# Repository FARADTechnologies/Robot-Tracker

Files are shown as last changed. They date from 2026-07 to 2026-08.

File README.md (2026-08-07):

# Robot Tracker

An end-to-end GNSS vehicle tracker: an ESP32-S3 + A7608E-H device reads its
position, **encrypts it with AES-256-GCM**, and publishes it over the cellular
network via MQTT. A browser dashboard subscribes, decrypts the payload
client-side and shows the vehicle live on a map.

Because the payload is encrypted before it leaves the device, the broker only
ever relays ciphertext — it never sees a real position.

```
[vehicle]  GNSS fix -> JSON -> AES-256-GCM -> MQTT over LTE
                                  |
                            [ MQTT broker ]         relays ciphertext only
                                  |
[browser]  MQTT over WebSocket -> decrypt in page -> live map + history
```

## Features

**Device**
- Multi-constellation GNSS (GPS + GLONASS + BeiDou + Galileo)
- AES-256-GCM payload encryption using the ESP32-S3 hardware accelerator
- Assisted GNSS (`AT+CAGPS`) for a faster, more reliable first fix
- Quality filtering: HDOP gating, impossible-jump rejection, stationary smoothing,
  and an optional HDOP-adaptive Kalman filter
- Adaptive reporting — frequent while moving, sparse while parked
- Store-and-forward buffer so positions survive cellular coverage gaps
- Remote configuration over MQTT (no USB required)
- Every feature can be toggled at runtime for debugging

**Dashboard**
- Live map with heading cone, accuracy circle, trail and dwell markers
- History scrubber with playback, and 15 min / 1 h / 1 day ranges
- Telemetry rail: speed, accuracy (±m and HDOP), satellites, altitude, heading
- Key vault — AES keys are typed in per session and kept in tab memory only
- Serial console (Web Serial) for direct AT access, plus an MQTT command tab
- Light and dark themes, English and Turkish, responsive down to phone size

## Repository layout

```
Firmware/
  gps_tracker/       main tracker firmware (config.example.h -> config.h)
  a7608_at_test/     modem bring-up sketch: AT, SIM, network, GNSS, HTTP
  gps/               minimal GNSS read example
  zenith_tracker/    early dashboard prototype
web/
  zenith.html        the dashboard (single file, no build step)
  config.example.js  copy to config.js and set broker + topics
tools/
  listen.py          subscribe and print decrypted positions
  send_command.py    send a downlink command to the device
  mock_walk.py       publish a fake track to exercise the UI
Mechanical/CAD/      enclosure and mounting design
docs/                hardware notes
```

## Hardware

| Part | Notes |
| --- | --- |
| ESP32-S3-N16R8 | 16 MB flash, 8 MB OPI PSRAM, hardware AES |
| A7608E-H | LTE Cat-4 modem with built-in multi-constellation GNSS |
| GNSS antenna | Ceramic patch — **mount it on a ≥70 × 70 mm ground plane** |
| LTE antenna | Full band 698–960 / 1710–2690 MHz |
| Power | 4S Li-ion pack + BMS -> buck converter -> 5 V rail |

Wiring between the two boards:

| ESP32-S3 | A7608E-H |
| --- | --- |
| GPIO15 (TX) | RXD |
| GPIO16 (RX) | TXD |
| GND | GND |

See [docs/hardware.md](docs/hardware.md) for power notes and accuracy tips.

## Getting started

### 1. Firmware

```bash
cp Firmware/gps_tracker/config.example.h Firmware/gps_tracker/config.h
# edit config.h: APN, broker, client id, topics, and your own AES key
openssl rand -hex 32          # generate a key
```

Build and upload with [arduino-cli](https://arduino.github.io/arduino-cli/):

```bash
arduino-cli core install esp32:esp32
arduino-cli compile --fqbn esp32:esp32:esp32s3:PSRAM=opi,FlashSize=16M,PartitionScheme=app3M_fat9M_16MB,CDCOnBoot=default,USBMode=hwcdc Firmware/gps_tracker
arduino-cli upload -p COM3 --fqbn esp32:esp32:esp32s3:PSRAM=opi,FlashSize=16M,PartitionScheme=app3M_fat9M_16MB,CDCOnBoot=default,USBMode=hwcdc Firmware/gps_tracker
```

The board exposes two USB-C ports: use the one wired to the USB-serial bridge for
flashing, and keep `CDCOnBoot=default` so the serial monitor works there.

### 2. Dashboard

```bash
cp web/config.example.js web/config.js    # set broker + topics
```

Open `web/zenith.html` in Chrome, Edge or Brave (Web Serial and Web Crypto are
required; both need a Chromium browser). Press **Connect**, then open the key
vault (🗝) and paste the device's 64-hex key. Nothing is stored on disk.

### 3. Tools

```bash
export TRACKER_KEY=<64 hex>
export TRACKER_TOPIC=yourprefix/trk01/pos
python tools/listen.py
```

## Remote configuration

Publish JSON to the device's command topic — from the dashboard's MQTT console
or with `tools/send_command.py`:

| Command | Effect |
| --- | --- |
| `{"interval":5}` | reporting period in seconds |
| `{"gnssms":1000}` | GNSS fix rate in ms (200–10000) |
| `{"hdopmax":2.5}` | reject fixes worse than this HDOP |
| `{"hdopgate":0}` | disable HDOP filtering |
| `{"statlock":0}` | disable stationary smoothing |
| `{"jumprej":0}` | disable jump rejection |
| `{"kalman":1}` | enable the Kalman filter |
| `{"agps":1}` | enable assisted GNSS |
| `{"antbias":0}` | stop feeding DC to the antenna (passive antenna) |
| `{"antmv":1800}` | antenna bias voltage in mV — also sets its LNA gain |
| `{"rlog":1}` | mirror the console to the log topic |
| `{"wifi":0}` | switch Wi-Fi and OTA off |
| `{"verbose":1}` | echo raw AT traffic to USB |
| `{"cmd":"report"}` | report position immediately |

Commands are themselves AES-256-GCM encrypted and carry a strictly increasing
`seq`, so the device rejects any command that is forged or replayed. The device
echoes its live settings back in the telemetry payload, so a command is confirmed
by the next message.

## Working without a cable

Once the tracker is mounted, USB is inconvenient. Three channels replace it:

- **Firmware over Wi-Fi.** The board joins the network named in `config.h`, or
  hosts one with that name if there is nothing to join, and listens for OTA:
  ```bash
  arduino-cli upload -p <device-ip> --protocol network --fqbn <same fqbn> Firmware/gps_tracker
  ```
  Joining an existing network is the better setup — hosting one means the laptop
  has to leave its own network to reach the board.
- **Console over MQTT.** `{"rlog":1}` mirrors log lines to the log topic,
  encrypted like everything else. Off by default because it costs airtime.
- **Console over USB.** Type a command as JSON, or send a raw `AT+...` straight
  to the modem. No sequence number is required there — the cable is already
  physical access, and it is the channel that still works when the radio link is
  the broken thing.

Telemetry carries `vbat`, the modem's supply voltage. Watch it: below about
3.7 V the LTE transmit bursts start failing and the modem drops off the network
before anything else visibly breaks.

## Security model

- **Confidentiality + authenticity both directions.** Positions (uplink) and
  commands (downlink) are AES-256-GCM. The broker only ever relays ciphertext, and
  the GCM tag means neither side accepts a forged or tampered message.
- **Replay protection.** Every frame carries a monotonic `seq`. The device rejects
  commands whose seq does not increase (counter persisted in NVS, so it survives
  reboots), and the dashboard drops stale or out-of-order positions.
- **Per-device keys.** Each device gets its own AES-256 key, so one leaked key
  cannot expose the rest.
- **Keys never committed.** `config.h` and `web/config.js` are untracked. The
  dashboard holds a key in tab memory only — never in localStorage, never shown
  back in plaintext. For the strongest setup keep keys offline (on paper) and type
  them into the vault per session.
- **Subresource Integrity.** The dashboard's CDN dependencies are pinned with
  SRI hashes, so a compromised CDN cannot inject code into a page that handles keys.

## Accuracy notes

Reported accuracy tracks HDOP closely (roughly ±HDOP × 5 m). With a clear view of
the sky the device typically sees 30+ satellites at HDOP below 1.5.

The single biggest cheap improvement is the antenna ground plane: a bare ceramic
patch on a small PCB loses several dB of gain and, more importantly, its circular
polarisation degrades — which is exactly what rejects reflected (multipath)
signals. Mount the patch on a metal plate of at least 70 × 70 mm, ceramic facing
the sky. An active antenna with a built-in LNA is the next step up.

## Roadmap

- IMU dead reckoning for tunnels and urban canyons
- Server-side map matching and persistent history (Supabase, then a dedicated backend)
- Authenticated broker with TLS, multi-device management
- Keys burned into the ESP32-S3 eFuse so firmware cannot read them back
- Geofencing and alerts, battery and ignition telemetry

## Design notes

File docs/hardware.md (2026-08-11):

# Hardware notes

## Power

```
4S Li-ion pack (12.8–16.8 V) -> BMS (4S 40A) -> LM2596 buck -> 5.15 V
                                                     |
                            star split at the buck output, separate wires:
                                     ├── ESP32-S3 board 5Vin
                                     └── A7608E-H breakout V
```

The modem's ~2 A LTE transmit bursts must **not** flow through the ESP32 board —
split the rail at the buck output and run separate pairs to each board. Measured
5.06 V at the common point under load.

### Protection board

The 4S board (marked `4S 40A`, `YS-Z1053`) carries two groups of pads that are
easy to confuse:

| Pads | Purpose |
| --- | --- |
| `0V` `4.2V` `8.4V` `12.6V` `16.8V` | balance and sense taps, one per cell junction |
| `J1` (+) `J2` (−) | the output port |

There is no separate charge terminal, so charge and discharge share `J1`/`J2`.
Both the buck converter and the charging socket hang off those two pads.

The taps double as the pack connection — `16.8V` is the pack positive and `0V`
the negative, so there is no extra `B+` wire. Verify them with a meter before
trusting the pack: each adjacent pair should read one cell, and the spread
between cells should stay under 0.1 V. Measured 2026-08-11 with the tracker
running: 3.66 / 3.66 / 3.64 / 3.72 V, pack 14.57 V, cells within 0.08 V.

That same measurement showed **14.14 V at `J1`/`J2` against 14.57 V at the pack**
— a 0.4 V loss through the board at roughly 100 mA, which implies a poor joint
rather than the MOSFETs. Worth reflowing when the 5 V wiring is soldered.

A protection board is not a charger. It cuts off on overcharge, over-discharge
and overcurrent, but it produces no charging profile of its own — the source
still has to supply a proper 16.8 V constant-current/constant-voltage curve.

A bulk capacitor (≈1000 µF) across the 5 V rail near the modem is recommended.
Without it, LTE bursts can dip the rail; if the ESP32 reboots unexpectedly the
firmware prints the reset reason at boot, so look for `BROWNOUT` there.

## Serial links

| ESP32-S3 | A7608E-H | Note |
| --- | --- | --- |
| GPIO15 | RXD | 3.3 V TTL, no level shifter needed |
| GPIO16 | TXD | |
| GND | GND | common ground required |

Modem default baud rate is 115200 and the AT set is SIM7600-compatible.

The dev board has two USB-C connectors:

- **UART port** (via the USB-serial bridge) — use this for flashing and the
  serial monitor, with `CDCOnBoot=default`.
- **Native USB port** (ESP32-S3 USB-Serial/JTAG) — works too, but then the build
  needs `CDCOnBoot=cdc` or the monitor stays blank.

## Antennas

Two separate connectors: one for LTE, one for GNSS. **Never transmit without the
LTE antenna attached.**

The GNSS ceramic patch needs a ground plane to perform. On a bare breakout the
plane is only the tiny PCB, which costs 2–3 dB of gain, shifts the centre
frequency, and degrades the antenna's right-hand circular polarisation towards
linear. That polarisation is what rejects reflected signals, so a small plane
directly worsens multipath error — the wandering you see in built-up areas.

Mount the patch on a metal plate of at least 70 × 70 mm with the ceramic facing
the sky, away from metal and from the vehicle body edge.

To tell an active antenna (with an internal LNA) from a passive one, measure
resistance between the coax centre and shield: a passive patch reads a short or
an open and is symmetric, while an active one reads a few hundred ohms to a few
kΩ and changes when the probes are reversed.

### Powering an active antenna

The module feeds DC to the antenna over the coax from its `VDD_AUX` pin, and an
active antenna is the module's default assumption. Two AT commands control it:

| Command | Effect |
| --- | --- |
| `AT+CVAUXS=1` / `=0` | enable or disable the bias |
| `AT+CVAUXV=<mV>` | bias voltage: 1200, 1250, 1700, 1800, 1850, 1900, 2500–3300 |

Turn the bias **off** for a passive antenna. The firmware exposes both as
`{"antbias":0|1}` and `{"antmv":1800}`.

The voltage matters for more than power: on most active antennas it also sets the
LNA gain. The module wants **under 18 dB total gain** at its port (its reference
figure is a 20 dB LNA), so a high-gain antenna on a long coax can overshoot and
compress the front end. Subtract the cable loss (RG174 is roughly 1 dB/m at
1.5 GHz) from the antenna's LNA gain, and drop the bias voltage if the result is
still well above 18 dB.

### Fitting an antenna with the wrong connector

Antennas often ship with SMA while the module board uses u.FL (IPEX MHF-I). Chain
them as **coax → SMA male → SMA female-to-u.FL pigtail → board**. A u.FL connector
cannot go directly onto RG174: u.FL is made for 1.13 mm micro-coax, RG174 is 2.8 mm.

Never improvise a splice at 1.5 GHz. A twisted joint wrecks the 50 Ω impedance and
throws away more than the antenna gains. Fit a proper connector, then check for a
short between centre and shield before plugging it into the module — a shorted
antenna shorts the module's bias supply.

Cable length is a design knob, not just a nuisance: RG174 costs roughly 1 dB/m at
1.5 GHz, which usefully offsets a high-gain active antenna. Around 1 m of cable
with the bias at 1800 mV lands close to the module's recommended input level.

### Antenna passband and constellations

Check the antenna's passband against the constellations you want. The module
receives GPS/Galileo at 1575.42 MHz, GLONASS at 1597.5–1605.8 MHz, and BeiDou B1I
at 1561.098 MHz. A GPS/GLONASS antenna specified from 1574 MHz upwards covers the
first two but filters BeiDou out — so switching antennas can change which
constellations appear in `AT+CGNSSINFO`, not just the signal quality.

## Status LED (NETLIGHT)

| Pattern | Meaning |
| --- | --- |
| Steady on | searching for network |
| 200 ms on / 200 ms off | registered on LTE, data ready |
| 800 ms on / 800 ms off | registered on 2G/3G |
| Off | no power or asleep |

## Accuracy checklist

1. Ground plane under the GNSS patch, clear view of the sky.
2. Assisted GNSS enabled (`AT+CAGPS`) — costs only tens of kB, valid for days.
3. HDOP gating on; reported accuracy is roughly ±HDOP × 5 m.
4. Raise the fix rate (`{"gnssms":1000}`) — commercial trackers run at 1–10 Hz.
5. Add an IMU for dead reckoning where the sky is blocked.

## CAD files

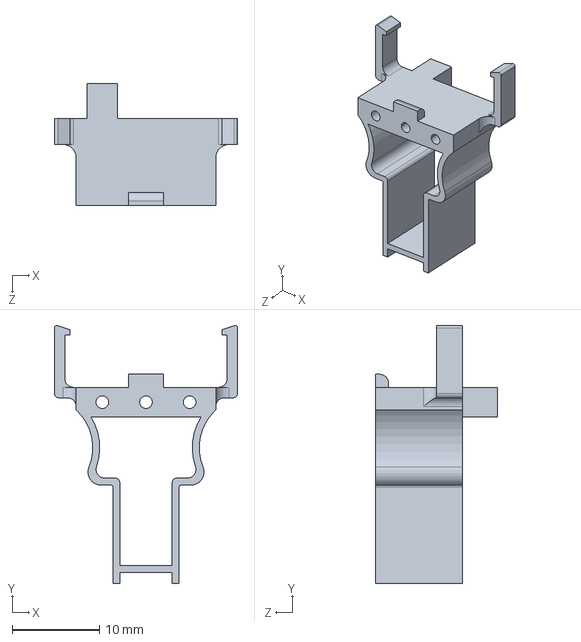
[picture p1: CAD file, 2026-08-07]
Mechanical/CAD/Assembly/batteryhold530-0415.stp.SLDPRT
21.0 x 29.6 x 14.0 mm

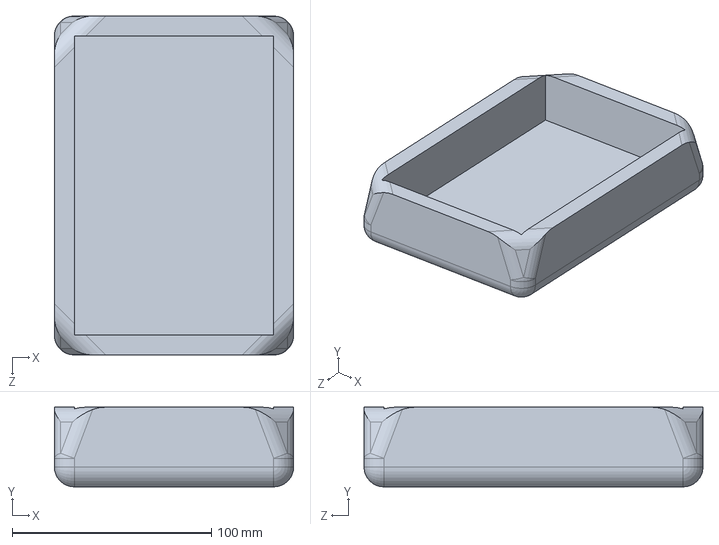
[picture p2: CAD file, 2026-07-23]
Mechanical/CAD/V1/Gövde.SLDPRT
120.0 x 40.0 x 170.0 mm

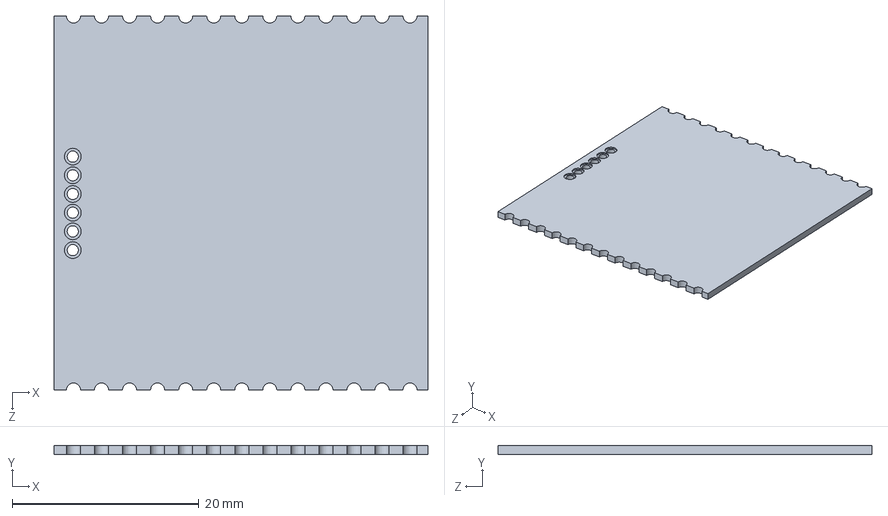
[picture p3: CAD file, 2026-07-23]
Mechanical/CAD/V1/A7608H Plata.SLDPRT
40.0 x 1.00 x 40.0 mm

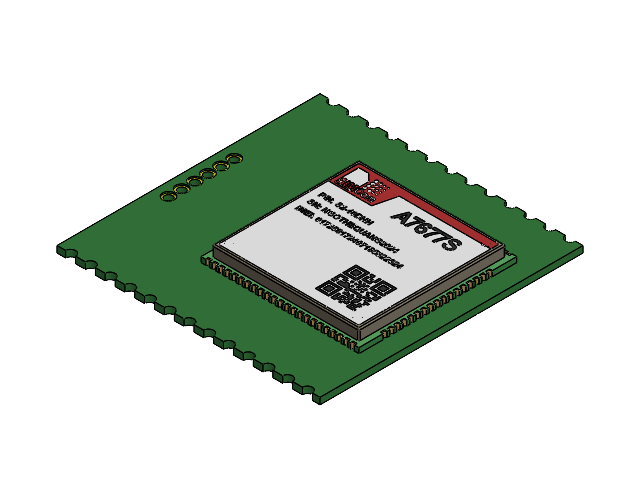
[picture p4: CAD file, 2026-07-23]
Mechanical/CAD/V1/A7608H Module.SLDASM
A7677S
A7608H Plata

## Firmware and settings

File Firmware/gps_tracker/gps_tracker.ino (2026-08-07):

/*
 * GPS Tracker - Phase 3 firmware
 * ESP32-S3-N16R8 + A7608E-H
 *
 * Pipeline: GNSS fix -> compact JSON -> AES-256-GCM -> base64 -> MQTT over LTE.
 * Payload is ciphertext, so even a public broker is a zero-knowledge relay.
 *
 * Phase 3 adds (for real-world / rural use):
 *  - ADAPTIVE REPORTING: fast cadence while the vehicle moves, slow while parked
 *    (+ an immediate report on every moving<->parked transition). Saves data.
 *  - STORE-AND-FORWARD: if a publish fails (no coverage), the reading is queued
 *    in a RAM ring buffer with its own GNSS timestamp; the queue is flushed
 *    (oldest first) once the link is back. No positions lost in rural gaps.
 *  - AUTO-RECOVER: re-power GNSS if it drops (CGNSSINFO -> ERROR), and
 *    re-establish MQTT if a publish fails.
 *
 * Working without USB:
 *  - Firmware goes over Wi-Fi (ArduinoOTA) once the board has joined a network,
 *    so the board only needs power. Wi-Fi is a bench convenience; the tracker
 *    still works with it switched off.
 *  - Logs can be mirrored to an MQTT topic (encrypted like everything else), so
 *    the console is readable from anywhere. Off by default to save airtime.
 *
 * Board settings (upload via right "COM" port = CH343 = COM3):
 *   FQBN esp32:esp32:esp32s3 PSRAM=opi FlashSize=16M CDCOnBoot=default
 *        USBMode=hwcdc UploadSpeed=921600
 * Blob published = base64( IV(12) || ciphertext || GCM-tag(16) )  (Web-Crypto compatible)
 */

#include <math.h>
#include <WiFi.h>
#include <WebServer.h>
#include <ArduinoOTA.h>
#include <Preferences.h>
#include "esp_system.h"
#include "mbedtls/gcm.h"
#include "mbedtls/base64.h"

// ---------------- config ----------------
#define MODEM_BAUD   115200
#define MODEM_RX_PIN 16
#define MODEM_TX_PIN 15

// Private settings live in config.h (APN, broker, client id, topics, DEVICE_ID and
// the 32-byte AES_KEY). That file is untracked — copy config.example.h to config.h
// and fill in your own values before building.
#include "config.h"

// Adaptive cadence
// NOTE: TEST values (frequent, so the web-app trail/trajectory is visible while
// walking). For data-saving production use: MOVING_MS 20000 / PARKED_MS 300000 / MOVE_DIST_M 12.
#define MOVE_DIST_M    5.0         // >5 m between 3 s fixes => moving
#define GNSS_POLL_MS   3000UL

// Store-and-forward
#define BUF_CAP        240         // queued readings when offline (~240 * ~130 B)

HardwareSerial &Modem = Serial1;

// state
bool     gnssPowered = false;
bool     mqttUp      = false;
uint32_t lastGnssPoll = 0;
uint32_t lastReport   = 0;
uint32_t lastMqttTry  = 0;
// Modem supply voltage. Below ~3.7 V the LTE transmit bursts start failing and
// the modem silently drops off the network, so this is worth watching.
float    vbat = 0;
uint32_t lastVbat = 0;
uint32_t movMs = 1000, parkMs = 1000;  // report interval (ms); adjustable via MQTT {"interval":sec}
String   rxAccum;                       // accumulates modem bytes for downlink parsing

/* ---- ACCURACY FEATURES: every one runtime-toggleable for debugging ----
   Downlink: {"agps":0|1,"hdopgate":0|1,"statlock":0|1,"jumprej":0|1,"hdopmax":3.0}
   Also {"cmd":"agpsnow"|"lbs"|"report"}                                        */
bool  F_AGPS     = true;    // AT+CAGPS assisted GNSS (ephemeris over LTE, tiny data)
bool  F_HDOPGATE = true;    // drop fixes whose HDOP is too poor
bool  F_STATLOCK = true;    // heavy smoothing while parked (kills wander)
bool  F_JUMPREJ  = true;    // reject physically impossible jumps
bool  F_LBS      = false;   // cell-tower fallback (off until verified on Azercell)
bool  F_KALMAN   = false;   // 1-D Kalman per axis, HDOP-adaptive (test outdoors before enabling)
bool  F_VERBOSE  = false;   // echo raw AT traffic to USB. OFF keeps the console readable at 1 Hz.
/* An active GNSS antenna is powered by DC on the coax (the module's VDD_AUX pin).
   The voltage also sets the antenna's LNA gain, so it is the knob that matches the
   antenna to the module's recommended input level (< 18 dB total, after cable loss).
   Turn the bias OFF for a passive antenna — SIMCom explicitly recommends that. */
bool  F_ANTBIAS  = true;
int   ANT_MV     = 3000;    // allowed: 1200,1250,1700,1800,1850,1900,2500..3300
/* Bench conveniences so the board never has to be tethered to USB:
   F_WIFI  — join Wi-Fi at boot and accept OTA firmware uploads
   F_RLOG  — mirror the console to an MQTT topic (encrypted, costs airtime) */
bool  F_WIFI     = true;
bool  F_RLOG     = false;
bool  otaBusy    = false;   // pause the modem loop while flashing
bool  otaReady   = false;   // true once the OTA port is listening (station OR hosted network)
/* When the radio link dies there is otherwise no way to ask the device what is
   wrong, even with Wi-Fi working. This serves that answer over HTTP. */
WebServer http(80);
bool  httpReady  = false;
String logBuf;
uint32_t lastLogPub = 0;
double kfLat = 0, kfLon = 0, kfP = 100;   // filter state + covariance
float HDOP_MAX   = 3.0;     // reject above this
float JUMP_MAX_MPS = 60.0;  // 216 km/h — anything faster is noise
uint32_t rejCount = 0, lastFixMs = 0;

/* Replay protection. Both directions carry a strictly increasing sequence number.
   Counters survive reboots via NVS, so an attacker cannot replay an old frame
   after power-cycling the device. Uplink counters are reserved in blocks to keep
   flash wear low at 1 Hz reporting. */
Preferences prefs;
uint32_t upSeq = 0, upSeqPersisted = 0, cmdRejected = 0;
// Command sequence numbers are wall-clock milliseconds, which overflow 32 bits.
uint64_t lastCmdSeq = 0;
#define SEQ_BLOCK 100
/* A restart looks exactly like a coverage gap from the outside, so count them
   and send the number along. A jump in this value explains a hole in the track
   that would otherwise be blamed on the sky. */
uint32_t bootCount = 0;
uint32_t lastBeat = 0;      // heartbeat while there is no fix
uint32_t gnssMs = 1000;     // GNSS fix rate (ms). Commercial trackers run 1-10 Hz; we were at 0.33 Hz.

bool   haveFix = false;
double fixLat = 0, fixLon = 0;
String fixAlt, fixSpd, fixHdop, fixUtc, fixDate, fixSats;

bool   moving = false;              // current motion state
bool   havePrevFix = false;
double prevLat = 0, prevLon = 0;    // anchor for the multi-second motion window
uint32_t prevRefMs = 0, stillSince = 0;
bool   reportedOnce = false;        // force one report on the very first fix

// ring buffer of plaintext JSON payloads (encrypted fresh at send time)
String  qbuf[BUF_CAP];
int     qHead = 0, qCount = 0;

// Print a console line and, when remote logging is on, queue it for the log
// topic so the same message is readable without a USB cable.
void say(const String &s) {
  Serial.println(s);
  if (!F_RLOG) return;
  logBuf += s; logBuf += '\n';
  if (logBuf.length() > 1400) logBuf.remove(0, logBuf.length() - 1400);
}

// Modem commands block for seconds at a time. Servicing OTA inside those waits
// keeps the board answerable to a firmware upload at any moment, instead of only
// in the gaps between commands.
/* Modem commands block for tens of seconds, and while the SIM is missing the
   loop spends nearly all its time inside them — so OTA and HTTP have to be
   served from in here or they are never served at all. The depth counter keeps
   that safe: it marks when a command is in flight so the /at endpoint declines
   rather than talking over it on the same UART. */
int modemDepth = 0;
struct ModemLock { ModemLock() { modemDepth++; } ~ModemLock() { modemDepth--; } };

inline void otaPump() {
  if (otaReady) ArduinoOTA.handle();
  if (httpReady) http.handleClient();
}

// ---------------- AT helpers ----------------
bool waitFor(const char *token, uint32_t timeoutMs, String &out) {
  uint32_t start = millis(); out = "";
  while (millis() - start < timeoutMs) {
    while (Modem.available()) {
      char c = (char)Modem.read(); out += c; if (F_VERBOSE) Serial.write(c);
      if (out.indexOf(token) >= 0) return true;
    }
    otaPump();
    delay(3);
  }
  return false;
}

bool sendAT(const char *cmd, const char *expect, uint32_t timeoutMs) {
  ModemLock lk;
  while (Modem.available()) Modem.read();
  if (F_VERBOSE) { Serial.print("\r\n>> "); Serial.println(cmd); }
  Modem.print(cmd); Modem.print("\r\n");
  String out; bool matched = (expect == nullptr || expect[0] == '\0');
  uint32_t start = millis();
  while (millis() - start < timeoutMs) {
    while (Modem.available()) {
      char c = (char)Modem.read(); out += c; if (F_VERBOSE) Serial.write(c);
      if (!matched && out.indexOf(expect) >= 0) matched = true;
    }
    if ((out.indexOf("OK\r\n") >= 0 || out.indexOf("ERROR") >= 0) && matched) break;
    otaPump();
    delay(3);
  }
  return matched;
}

// Send a command and hand back the modem's raw reply, for answers that need parsing.
String atReply(const char *cmd, uint32_t timeoutMs) {
  ModemLock lk;
  while (Modem.available()) Modem.read();
  if (F_VERBOSE) { Serial.print("\r\n>> "); Serial.println(cmd); }
  Modem.print(cmd); Modem.print("\r\n");
  String out; uint32_t start = millis();
  while (millis() - start < timeoutMs) {
    while (Modem.available()) { char c = (char)Modem.read(); out += c; if (F_VERBOSE) Serial.write(c); }
    if (out.indexOf("OK\r\n") >= 0 || out.indexOf("ERROR") >= 0) break;
    otaPump();
    delay(3);
  }
  return out;
}

bool sendPrompted(const String &cmd, const uint8_t *data, size_t len) {
  ModemLock lk;
  while (Modem.available()) Modem.read();
  if (F_VERBOSE) { Serial.print("\r\n>> "); Serial.println(cmd); }
  Modem.print(cmd); Modem.print("\r\n");
  String r;
  if (!waitFor(">", 3000, r)) return false;
  Modem.write(data, len);
  return waitFor("OK", 5000, r);
}

// ---------------- crypto ----------------
size_t encryptPayload(const String &plain, uint8_t *out, size_t outCap) {
  const size_t ivLen = 12, tagLen = 16;
  size_t ptLen = plain.length();
  if (ivLen + ptLen + tagLen > outCap) return 0;
  uint8_t *iv = out, *ct = out + ivLen, *tag = out + ivLen + ptLen;
  for (size_t i = 0; i < ivLen; i++) iv[i] = (uint8_t)(esp_random() & 0xFF);
  mbedtls_gcm_context gcm; mbedtls_gcm_init(&gcm);
  if (mbedtls_gcm_setkey(&gcm, MBEDTLS_CIPHER_ID_AES, AES_KEY, 256) != 0) { mbedtls_gcm_free(&gcm); return 0; }
  int rc = mbedtls_gcm_crypt_and_tag(&gcm, MBEDTLS_GCM_ENCRYPT, ptLen, iv, ivLen, nullptr, 0,
                                     (const uint8_t*)plain.c_str(), ct, tagLen, tag);
  mbedtls_gcm_free(&gcm);
  return rc == 0 ? ivLen + ptLen + tagLen : 0;
}

String base64Of(const uint8_t *data, size_t len) {
  size_t need = 0; mbedtls_base64_encode(nullptr, 0, &need, data, len);
  uint8_t *buf = (uint8_t*)malloc(need + 1); if (!buf) return String();
  size_t wrote = 0; mbedtls_base64_encode(buf, need + 1, &wrote, data, len); buf[wrote] = 0;
  String s = String((char*)buf); free(buf); return s;
}

// Decrypt a base64( IV(12) || ciphertext || tag(16) ) blob. Returns "" if the
// GCM tag does not verify — i.e. wrong key or tampered/forged command.
String decryptPayload(const String &b64) {
  size_t inLen = b64.length();
  uint8_t *raw = (uint8_t*)malloc(inLen); if (!raw) return String();
  size_t rawLen = 0;
  if (mbedtls_base64_decode(raw, inLen, &rawLen, (const uint8_t*)b64.c_str(), inLen) != 0 ||
      rawLen < 12 + 16 + 1) { free(raw); return String(); }
  const size_t ivLen = 12, tagLen = 16, ptLen = rawLen - ivLen - tagLen;
  uint8_t *iv = raw, *ct = raw + ivLen, *tag = raw + ivLen + ptLen;
  uint8_t *pt = (uint8_t*)malloc(ptLen + 1); if (!pt) { free(raw); return String(); }
  mbedtls_gcm_context gcm; mbedtls_gcm_init(&gcm);
  int rc = -1;
  if (mbedtls_gcm_setkey(&gcm, MBEDTLS_CIPHER_ID_AES, AES_KEY, 256) == 0)
    rc = mbedtls_gcm_auth_decrypt(&gcm, ptLen, iv, ivLen, nullptr, 0, tag, tagLen, ct, pt);
  mbedtls_gcm_free(&gcm);
  String out;
  if (rc == 0) { pt[ptLen] = 0; out = String((char*)pt); }
  free(raw); free(pt);
  return out;                                   // empty on auth failure
}

// ---------------- geo ----------------
double distMeters(double la1, double lo1, double la2, double lo2) {
  const double R = 6371000.0, d = 0.017453292519943295;
  double dla = (la2 - la1) * d, dlo = (lo2 - lo1) * d;
  double a = sin(dla/2)*sin(dla/2) + cos(la1*d)*cos(la2*d)*sin(dlo/2)*sin(dlo/2);
  return 2 * R * asin(sqrt(a));
}

// ---------------- LTE + GNSS ----------------
int splitFields(const String &s, String f[], int maxF) {
  int n = 0, start = 0;
  while (n < maxF) {
    int c = s.indexOf(',', start);
    if (c < 0) { f[n++] = s.substring(start); break; }
    f[n++] = s.substring(start, c); start = c + 1;
  }
  return n;
}

bool lteUp() {
  bool alive = false;
  for (int i = 0; i < 10 && !alive; i++) { alive = sendAT("AT", "OK", 1500); if (!alive) delay(800); }
  if (!alive) return false;
  sendAT("ATE0", "OK", 1500);
  sendAT("AT+CPIN?", "READY", 3000);
  sendAT("AT+CMGD=1,4", nullptr, 5000);   // clear SMS storage; a full store blocks the modem
  sendAT("AT+CGDCONT=1,\"IP\",\"" APN "\"", "OK", 3000);
  // Wait for real packet registration. MQTT cannot connect before the network
  // is attached, and after a cold boot that takes tens of seconds.
  for (int i = 0; i < 40; i++) {
    String r = atReply("AT+CGREG?", 2000);
    int k = r.indexOf("+CGREG:");
    if (k >= 0) {
      int c = r.indexOf(',', k);
      if (c > 0) {
        int st = r.substring(c + 1, c + 2).toInt();     // 1 = home, 5 = roaming
        if (st == 1 || st == 5) { say(String("[lte] registered after ") + i + " s"); return true; }
      }
    }
    delay(1000);
  }
  say("[lte] no packet registration yet");
  return false;
}

void gnssOn() {
  sendAT("AT+CGNSSPWR=1", "OK", 5000);
  String r; waitFor("READY!", 15000, r);
  gnssPowered = true;
}

// Poll one CGNSSINFO; updates fix + motion state. Auto-recovers GNSS if it dropped.
void pollGnss() {
  String resp;
  while (Modem.available()) Modem.read();
  if (F_VERBOSE) Serial.print("\r\n>> AT+CGNSSINFO\r\n");
  Modem.print("AT+CGNSSINFO\r\n");
  waitFor("OK", 3000, resp);

  int idx = resp.indexOf("+CGNSSINFO:");
  if (idx < 0) {
    if (resp.indexOf("ERROR") >= 0) {          // GNSS powered off (e.g. modem reset)
      Serial.println("   [GNSS] dropped -> re-powering");
      gnssOn();
    }
    return;
  }
  String data = resp.substring(idx + 11); data.trim();
  String f[20]; int n = splitFields(data, f, 20);
  for (int i = 0; i < n; i++) f[i].trim();

  int li = -1;
  for (int i = 1; i + 1 < n; i++)
    if ((f[i+1] == "N" || f[i+1] == "S") && f[i].length() && isDigit(f[i][0])) { li = i; break; }
  if (f[0].length() == 0 || li < 0) {
    static uint32_t lastSaid = 0;              // once a second is noise; say it rarely
    if (millis() - lastSaid > 15000) { lastSaid = millis(); Serial.println("   [GNSS] searching, no fix yet"); }
    return;
  }

  double lat = f[li].toDouble();   if (f[li+1] == "S") lat = -lat;
  double lon = f[li+2].toDouble(); if (f[li+3] == "W") lon = -lon;
  double hd  = (li+10 < n) ? f[li+10].toDouble() : 0.0;

  /* ---------- quality filters (toggleable) ---------- */
  if (F_HDOPGATE && hd > HDOP_MAX) {
    rejCount++; Serial.printf("   [GNSS] REJECT hdop %.1f > %.1f\r\n", hd, HDOP_MAX); return; }
  if (F_JUMPREJ && haveFix) {
    double dt = (millis() - lastFixMs) / 1000.0; if (dt < 0.2) dt = 0.2;
    double d  = distMeters(fixLat, fixLon, lat, lon);
    if (d / dt > JUMP_MAX_MPS) {
      rejCount++; Serial.printf("   [GNSS] REJECT jump %.0f m in %.1f s\r\n", d, dt); return; }
  }
  /* ---------- motion detection ----------
     Comparing one fix to the next cannot see a walk: a pedestrian covers about
     1.4 m per second, which sits inside the receiver's own noise. Measure the
     displacement over a few seconds instead, where real movement clears the
     noise comfortably. Speed from the receiver is a second opinion. */
  bool wasMoving = moving;
  double spdKmh = (li + 7 < n) ? f[li + 7].toDouble() : 0.0;
  if (!havePrevFix) { prevLat = lat; prevLon = lon; prevRefMs = millis(); havePrevFix = true; }
  double refDt = (millis() - prevRefMs) / 1000.0;
  double refD  = distMeters(prevLat, prevLon, lat, lon);
  if (refDt >= 4.0) {                       // decide on a 4 s window, then re-anchor
    moving = (refD >= 6.0) || (spdKmh > 1.5);
    prevLat = lat; prevLon = lon; prevRefMs = millis();
  } else if (refD >= 6.0 || spdKmh > 1.5) { // obvious movement: react immediately
    moving = true;
    prevLat = lat; prevLon = lon; prevRefMs = millis();
  }

  /* Stationary smoothing exists to stop a parked marker wandering, but it must
     never fight real travel. Engage only once genuinely still, blend gently, and
     abandon it the moment the raw fix walks away from the held position. */
  if (F_STATLOCK && haveFix && !moving) {
    if (wasMoving) stillSince = millis();
    if (millis() - stillSince > 8000 && distMeters(fixLat, fixLon, lat, lon) < 8.0) {
      lat = fixLat * 0.7 + lat * 0.3;
      lon = fixLon * 0.7 + lon * 0.3;
    }
  } else {
    stillSince = millis();
  }
  /* optional Kalman: measurement noise scales with HDOP, process noise with motion */
  if (F_KALMAN) {
    if (!haveFix) { kfLat = lat; kfLon = lon; kfP = 100; }
    else {
      double R = (hd > 0 ? hd : 1.0) * 5.0; R *= R;          // metres^2 from HDOP
      double Q = moving ? 9.0 : 0.25;                        // trust motion less when parked
      kfP += Q;
      double K = kfP / (kfP + R);
      kfLat += K * (lat - kfLat); kfLon += K * (lon - kfLon);
      kfP *= (1 - K);
      lat = kfLat; lon = kfLon;
    }
  }

  fixLat = lat; fixLon = lon; lastFixMs = millis();
  fixDate = (li+4 < n) ? f[li+4] : "";
  fixUtc  = (li+5 < n) ? f[li+5] : "";
  fixAlt  = (li+6 < n) ? f[li+6] : "";
  fixSpd  = (li+7 < n) ? f[li+7] : "";
  fixHdop = (li+10 < n) ? f[li+10] : "";
  { long t = 0; for (int i = 1; i < li; i++) t += f[i].toInt(); fixSats = String(t); }
  haveFix = true;

  Serial.printf("   [GNSS] lat=%.6f lon=%.6f hdop=%s sat=%s %s\r\n",
                lat, lon, fixHdop.c_str(), fixSats.c_str(), moving ? "MOVING" : "parked");

  if (!reportedOnce) {                  // first fix -> report right away
    reportedOnce = true;
    reportPosition();
    return;
  }
  if (moving != wasMoving) {            // report immediately on state change
    Serial.println(moving ? "   >> started moving" : "   >> stopped");
    reportPosition();
  }
}

// ---------------- MQTT ----------------
bool mqttConnect() {
  // Without a readable SIM the whole sequence below just burns forty seconds and
  // fails, and repeating that starves everything else in the loop. Check first.
  if (!sendAT("AT+CPIN?", "READY", 3000)) {
    static uint32_t lastMoan = 0;
    if (millis() - lastMoan > 60000) { lastMoan = millis(); say("!! SIM not readable — reseat it and power-cycle the modem"); }
    mqttUp = false; return false;
  }
  // Clean slate: MQTT state persists on the modem across ESP32 resets, so a
  // stale acquired/connected client (error 19) must be torn down first.
  sendAT("AT+CMQTTSTART", nullptr, 8000);       // ok whether or not already started
  delay(1500);                                  // the stack needs a moment before ACCQ
  sendAT("AT+CMQTTDISC=0,120", nullptr, 5000);  // drop any stale connection (ignore error)
  sendAT("AT+CMQTTREL=0", nullptr, 3000);       // release stale client (ignore error)
  String accq = String("AT+CMQTTACCQ=0,\"") + MQTT_CLIENTID + "\",0";
  sendAT(accq.c_str(), "OK", 3000);
  String conn = String("AT+CMQTTCONNECT=0,\"") + MQTT_BROKER + "\",60,1";
  if (!sendAT(conn.c_str(), "+CMQTTCONNECT: 0,0", 20000)) { say("!! MQTT connect failed"); mqttUp = false; return false; }
  mqttUp = true; say("*** MQTT connected ***");
  String st = String("AT+CMQTTSUBTOPIC=0,") + strlen(CMD_TOPIC) + ",1";
  sendPrompted(st, (const uint8_t*)CMD_TOPIC, strlen(CMD_TOPIC));
  sendAT("AT+CMQTTSUB=0", "OK", 5000);
  Serial.println("[downlink] subscribed to cmd topic");
  return true;
}

// Encrypt a plaintext JSON and publish it to any topic. Returns success.
bool publishTo(const char *topic, const String &json) {
  uint8_t blob[768];
  size_t blobLen = encryptPayload(json, blob, sizeof(blob));
  if (blobLen == 0) { Serial.println("!! encrypt failed (payload too big?)"); return false; }
  String b64 = base64Of(blob, blobLen);
  String tCmd = String("AT+CMQTTTOPIC=0,") + strlen(topic);
  if (!sendPrompted(tCmd, (const uint8_t*)topic, strlen(topic))) return false;
  String pCmd = String("AT+CMQTTPAYLOAD=0,") + b64.length();
  if (!sendPrompted(pCmd, (const uint8_t*)b64.c_str(), b64.length())) return false;
  return sendAT("AT+CMQTTPUB=0,1,60", "+CMQTTPUB: 0,0", 10000);
}
bool publishJson(const String &json) { return publishTo(TOPIC, json); }
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
void loop() {
  if (otaReady) ArduinoOTA.handle();
  if (otaBusy) return;                       // flashing owns the CPU
  if (httpReady) http.handleClient();

  checkUsbCommand();
  checkDownlink();
  // Keep trying to reconnect even with no fix — otherwise a device that boots
  // before the network is up stays silent and unreachable by command.
  if (!mqttUp && millis() - lastMqttTry >= 20000) { lastMqttTry = millis(); mqttConnect(); }
  if (gnssPowered && millis() - lastGnssPoll >= gnssMs) { lastGnssPoll = millis(); pollGnss(); }
  uint32_t due = moving ? movMs : parkMs;
  if (millis() - lastReport >= due) reportPosition();
  if (millis() - lastVbat >= 30000) { lastVbat = millis(); readVbat(); }
  if (F_RLOG && millis() - lastLogPub >= 5000) { lastLogPub = millis(); publishLog(); }
}

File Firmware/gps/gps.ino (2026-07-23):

#include <Arduino.h>

#define RX2 16
#define TX2 17

// Değişkenler
float latitude = 0.0, longitude = 0.0;
int satelliteCount = 0;
String gsmBuffer = "";
unsigned long lastGPSRequest = 0;
const unsigned long GPS_INTERVAL = 1000; // Her 1 saniyede bir veri iste

void setup() {
  Serial.begin(115200);
  Serial2.begin(115200, SERIAL_8N1, RX2, TX2);
  Serial2.println("AT+CGNSSPWR=1");
  Serial.println("Gerçek Zamanlı Sistem Başlatıldı.");
}

void loop() {
  // 1. ZAMAN YÖNETİMİ (Delay Kullanmadan!)
  // İşlemci burada asla durmaz, sürekli döner
  if (millis() - lastGPSRequest >= GPS_INTERVAL) {
    Serial2.println("AT+CGNSSINFO");
    lastGPSRequest = millis();
  }

  // 2. VERİ OKUMA (Beklemeden!)
  // Veri geldikçe parça parça tampona (buffer) alınır
  while (Serial2.available()) {
    char c = Serial2.read();
    if (c == '\n') { // Satır bittiğinde (Veri tam geldiğinde) işle
      processResponse(gsmBuffer);
      gsmBuffer = ""; // Tamponu boşalt
    } else {
      gsmBuffer += c;
    }
  }

  // 3. BURADA DİĞER İŞLERİ YAPABİLİRSİN
  // İşlemci boşta kalmaz, örneğin sensör okuyabilir veya şifreleme yapabilir.
}

void processResponse(String data) {
  if (data.indexOf("+CGNSSINFO:") != -1) {
    parseGPS(data);
    Serial.printf("FIX [%d Uydu] -> Lat: %.7f | Lon: %.7f\n", satelliteCount, latitude, longitude);
  } else if (data.indexOf("OK") != -1) {
    // Komut onaylarını burada yakalayabiliriz
  }
}

void parseGPS(String data) {
  // Virgülleri sayan profesyonel parser
  int commaCount = 0;
  int startPos = data.indexOf(':') + 1;
  
  for (int i = 0; i < data.length(); i++) {
    if (data[i] == ',') {
      commaCount++;
      int nextComma = data.indexOf(',', i + 1);
      String val = data.substring(i + 1, nextComma);
      val.trim();

      if (commaCount == 1) satelliteCount = val.toInt();
      if (commaCount == 5 && val.length() > 0) latitude = val.toFloat();
      if (commaCount == 7 && val.length() > 0) longitude = val.toFloat();
    }
  }
}

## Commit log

2026-07-23 Initial commit: encrypted GNSS vehicle tracker
    Device firmware (ESP32-S3 + A7608E-H), browser dashboard, host tools and
    mechanical design.
    - AES-256-GCM encrypted position reporting over LTE/MQTT
    - Assisted GNSS, HDOP gating, jump rejection, stationary smoothing,
    optional Kalman filter, adaptive reporting, store-and-forward buffer
    - Remote configuration over MQTT with runtime feature flags
    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
    [A7608H Module.SLDASM, A7608H Plata.SLDPRT, Gövde.SLDPRT]
2026-07-26 Authenticate and replay-protect the command channel
    - Downlink commands are now AES-256-GCM encrypted; the device rejects any
    command that is not authenticated with its key
    - Every uplink and downlink frame carries a monotonic sequence number, so
    replayed or out-of-order frames are dropped (counters persist across reboots)
    - Pin CDN dependencies with Subresource Integrity hashes
    - Update tools and docs to match
    [gps_tracker.ino]
2026-08-01 Control the GNSS antenna bias supply from firmware
    An active antenna is powered over the coax, and on most of them that voltage
    also sets the LNA gain, so it needs to be tunable rather than fixed.
    - Apply the bias at boot, before GNSS power-on
    - Expose it as a runtime setting over the command channel
    - Document how to match antenna gain to the module input, and how an antenna's
    passband decides which constellations are received
    [gps_tracker.ino]
2026-08-01 Document fitting an antenna whose connector does not match the board
    Covers the coax to SMA to u.FL chain, why a u.FL connector cannot go straight
    onto RG174, the short-circuit check before connecting, and how cable length
    trades against the gain of a high-gain active antenna.
2026-08-07 Work on the tracker without a USB cable, and see the power rail
    Firmware upload now goes over Wi-Fi (ArduinoOTA), the console can be mirrored
    to an encrypted MQTT topic, and commands can also be typed into the USB console
    directly. That last channel matters: it is the one that still works when the
    radio link is the thing that is broken.
    Also fixes several problems found while testing:
    - Command sequence numbers are wall-clock milliseconds and overflowed a 32-bit
    parse, so every command after the first was rejected as a replay
    - The modem's packet registration was never actually awaited, and MQTT was only
    retried when a fix existed, so a device that booted before the network was up
    st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
    [batteryhold530-0415.stp.SLDPRT]
2026-08-07 Host a network for OTA when there is none to join
    Falling back to an access point means the board is reachable for wireless
    firmware updates anywhere, not only within range of a known network. Track
    readiness with its own flag, because a hosted network never reports
    WL_CONNECTED and OTA would other­wise never be serviced.
    Also clear SMS storage at startup; a full store blocks the modem.
2026-08-07 Document the cable-free channels and quieten the search log
    Saying "no fix yet" every second buries everything else in the console; once
    every fifteen seconds carries the same information.
    [gps_tracker.ino]
2026-08-07 Keep firmware updates responsive without starving the modem
    Two things learned from flashing the board wirelessly on real hardware.
    Modem commands block for seconds, and an upload arriving during one used to be
    missed entirely, so the first attempt would fail and only a retry got through.
    Servicing the update inside those waits makes the board answerable at any moment.
    Holding the Wi-Fi radio awake costs enough current to drag the shared 5 V rail
    down: measured supply fell from 3.86 V to 3.68 V, close to the point where LTE
    transmit bursts start failing. Leaving the radio's power saving on restores it
    to 4.02 V and updates still arrive.
    [gps_tracker.ino]
2026-08-07 Let the modem be interrogated over the radio
    Reading a raw AT reply used to need a cable, which is exactly the situation
    where a mounted tracker cannot help you. Commands may now carry an AT string and
    the answer comes back on the log topic.
    The first thing it found: this module accepts the antenna bias switch but
    rejects the voltage setting, so the reported bias voltage was a level that was
    never applied. Report what actually happened instead.
2026-08-07 Show what the device says back, and move the map instead of teleporting
    Remote commands looked like they did nothing: the console logged what it sent
    and then went quiet, because the app never listened to the device's log topic.
    It does now, so a command's effect is visible where the command was typed.
    Panning and fitting are animated, so the map travels to a selection rather than
    cutting to it and leaving you to work out where you ended up.
2026-08-07 Tell a restart apart from a coverage gap
    A walk log showed a two minute hole in the track with a straight line drawn
    across it. It was not lost signal: the reject counter had reset, so the board
    had restarted, and the boot sequence took exactly that long. Nothing in the
    telemetry said so, and nothing in the map suggested the line was invented.
    - Count boots and send the number, and name a brownout reset when it happens
    - Send a heartbeat while searching, so a device with no fix is still visibly
    alive rather than indistinguishable from a dead one
    - Start the receiver before the network. Satellites take the longest to come
    back, so they should not wait behind registration and assistance d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
    [gps_tracker.ino]
2026-08-07 Keep a walk after the tab is closed, and list past trips
    A fifteen minute walk was recorded perfectly by the device and then vanished,
    because the track only ever lived in the page. Points are now written to local
    storage and read back on load.
    On top of that, trips are derived from the stored track: a trip ends after half
    an hour without moving more than fifteen metres, or half an hour with no data.
    The trip list shows date, span, distance and duration, and picking one widens
    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
2026-08-07 Ask the device what is wrong when the radio link cannot
    A walk measured 372 m that was really more than a kilometre. The stationary
    smoother was the cause: motion was judged one fix against the next, but a walker
    covers about 1.4 m per second, which sits inside the receiver's own noise. The
    device therefore believed it was parked for four fifths of the walk and blended
    each new position 90/10 with the old one, dragging the track back on itself.
    Motion is now measured over several seconds, where walking clears the noise, and
    the smoother waits until the device has genuinely settled, blends gently, and
    lets go the moment the raw fix moves away.
    Diagnosing that took a cable, because a dead cel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
    [gps_tracker.ino]
2026-08-11 Write down what the protection board actually does
    Its pads fall into two groups that look alike and are not: five taps that sense
    and balance the cells, and two that carry the load. Charge and discharge share
    those two, which is worth knowing before wiring a charger to them.
    Measuring the taps also turned up 0.4 V lost across the board at a tenth of an
    amp, which is a joint rather than the switches, and the same fault that has been
    dogging the 5 V side.
